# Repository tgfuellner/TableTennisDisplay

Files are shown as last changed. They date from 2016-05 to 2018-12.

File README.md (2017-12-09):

# TableTennisDisplay
Display for counting Table Tennis Matches

## Components of the Display for Version 1 with 7-Segment LEDs

* esp8266 (Wemos D1 mini)
 * Send data to LED Driver Shift Register TLC5916IN 
 * queries state of the buttons
 * controlls the OLED display
 * Can be controled by mobile phone (mqtt or http)
 * implements counting behavieour
 * Runs with 3.3V

* Powered by 12V Lead Acid Battery

* DC-DC Converter for 3.3V

* Seven Segment Displays
 * 4 Big red LED common anode for the points
 * 2 smaller green LED common kathode for the games

* LED Driver Shift Register TLC5916IN 
 * [Datasheet](http://docs-europe.electrocomponents.com/webdocs/12f7/0900766b812f7b59.pdf)

* Small OLED Display ssd1306 for umpire feedback and guidance

## Components of the Display for Version 2 with Hub75 64x32 RGB Matrix

* esp8266 (Wemos D1 mini)
 * Send data to RGB Matrix over i2c to HUB75 Controler
 * queries state of the buttons
 * controlls the OLED display
 * implements counting behavieour
 * Runs with 3.3V

* Powered by Stock 5V USB Powerbank

* HUB75 64x32 RGB Matrix

* HUB75 Controler: Arduino Mega

* Small OLED Display ssd1306 for umpire feedback and guidance

## Components of the Display for Version 3 with Hub75 64x32 RGB Matrix

* esp8266 (Wemos D1 mini)
 * Send data to RGB Matrix over i2c to HUB75 Controler
 * queries state of the buttons
 * controlls the OLED display
 * implements counting behavieour
 * Runs with 3.3V

* Powered by Stock 5V USB Powerbank

* HUB75 64x32 RGB Matrix

* HUB75 Controler: Custom made Atmega128 board
 * See https://easyeda.com/thomas.gfuellner/TTDisplay64x32-LDrpmkwus

* Small OLED Display ssd1306 for umpire feedback and guidance

## Counting behaviour

* Game is won with 2 points difference and with more than 10 points
* Indicate who has to serve - changes every 2 points or every 1 point if a player has more than 10 points
* Recognise game won
 * write message on OLED
 * increase game count
 * after Button press: reset points and swap game display digits
* In the last game: swap side if one player reaches 5 points
 * write message to OLED
 * do swaping after pressing of a button 

## Setup
### Menu right after powering the display on

* Hold back button on Power on: Join a existing Wifi or make a own AP
* Which side serves first

### Menu after long button press
* Number of games to play:
 * default: 3 games of 5
 * 2 of 3
 * 4 of 7
 * 5 of 9
* LED Brightness

## HTTP
### Remote control over Wifi

* Press an hold right back button an power the Display on
* Choose own Network not connected to internet
* Join the Wifi Network created by the Display
 * The Name is e.g. TTDisplay3
 * Ip of Display is 192.168.4.1
* There are following actions:
 * http://192.168.4.1:8080/
 * http://192.168.4.1:8080/incrRight
 * http://192.168.4.1:8080/incrLeft
 * http://192.168.4.1:8080/decrRight
 * http://192.168.4.1:8080/decrLeft
 * http://192.168.4.1:8080/finishGame
 * http://192.168.4.1:8080/swapSide
 * http://192.168.4.1:8080/count
 * http://192.168.4.1:8080/reset
 * http://192.168.4.1:8080/rightServe
 * http://192.168.4.1:8080/leftServe
 * http://192.168.4.1:8080/setNames

## Installation
* Arduino
* https://github.com/esp8266/Arduino with Boardmanager
 * Boards manager link: http://arduino.esp8266.com/stable/package_esp8266com_index.json

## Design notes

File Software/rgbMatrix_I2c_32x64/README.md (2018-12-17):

# RGB Matrix for Atmega128

## Compile

* Arduino install: https://github.com/MCUdude/MegaCore
* Library "RGB matrix Panel"
  * sed -i 's/TIMSK1/TIMSK/' /home/thomas/Arduino/libraries/RGB_matrix_Panel/RGBmatrixPanel.cpp
  * sed -i  's/TIFR1/TIFR/' /home/thomas/Arduino/libraries/RGB_matrix_Panel/RGBmatrixPanel.cpp

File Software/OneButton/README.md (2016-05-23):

Port of the Arduino OneButton Library to esp8266 micropython
===

This libary is improving the usage of a singe button for input.
It shows how to use an digital input pin with a single pushbutton attached
for detecting some of the typical button press events like single clicks, double clicks and long-time pressing.
This enables you to reuse the same button for multiple functions and lowers the hardware invests.

This is also a sample for implementing simple finite-state machines by using the simple pattern above. 

You can find more detail on this library at
http://www.mathertel.de/Arduino/OneButtonLibrary.aspx

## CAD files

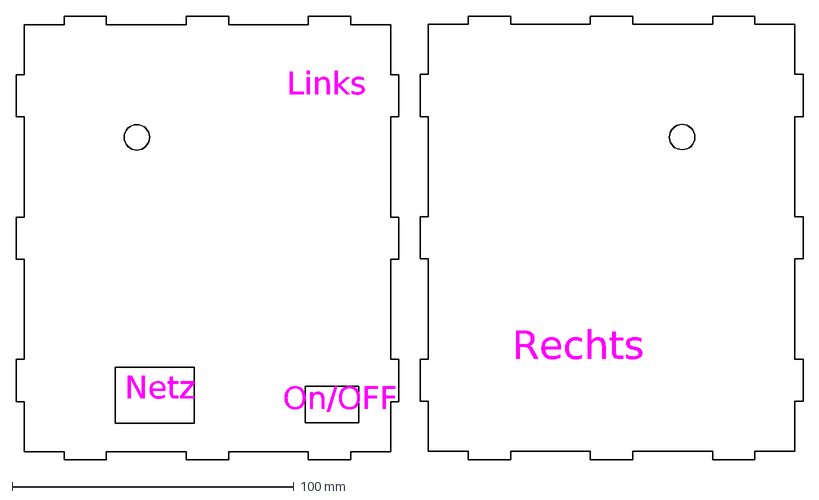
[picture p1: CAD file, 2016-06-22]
Case/bigBox-ForVersion1/sides.dxf
Links
On/OFF
Netz
Rechts

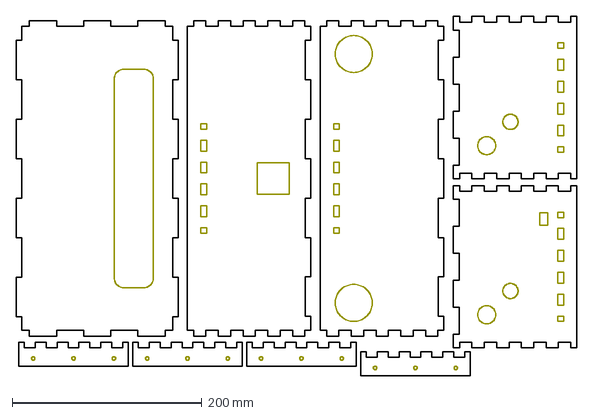
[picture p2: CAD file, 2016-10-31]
Case/rgbPanel/all-edited.dxf
590.5 x 378.0 mm

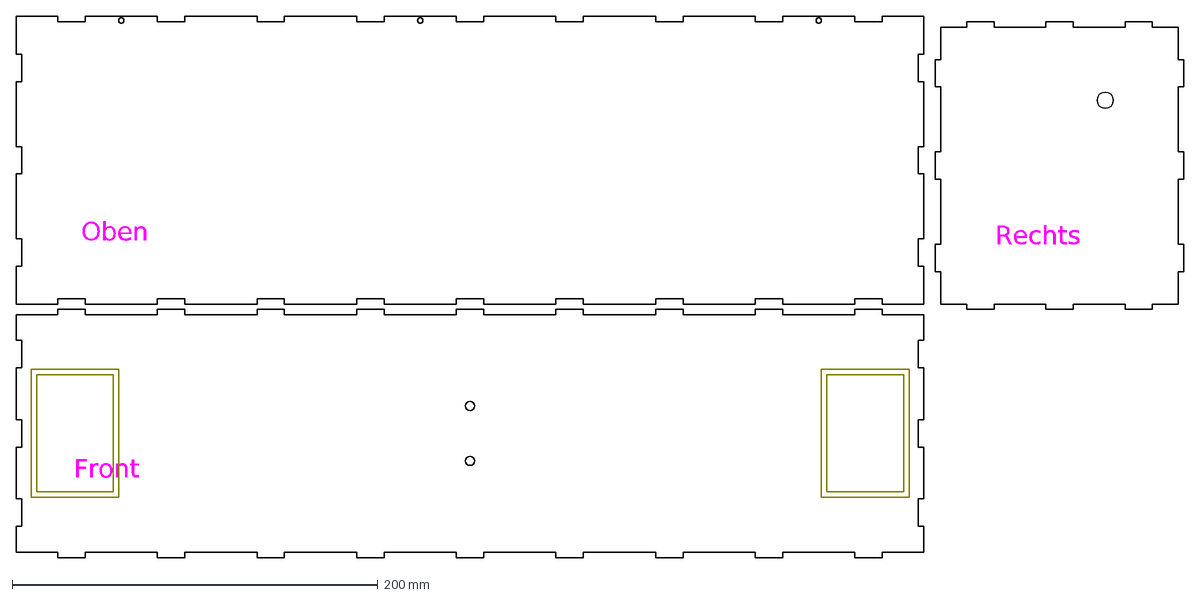
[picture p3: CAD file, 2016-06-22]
Case/bigBox-ForVersion1/box2.dxf
Oben
Front
Rechts

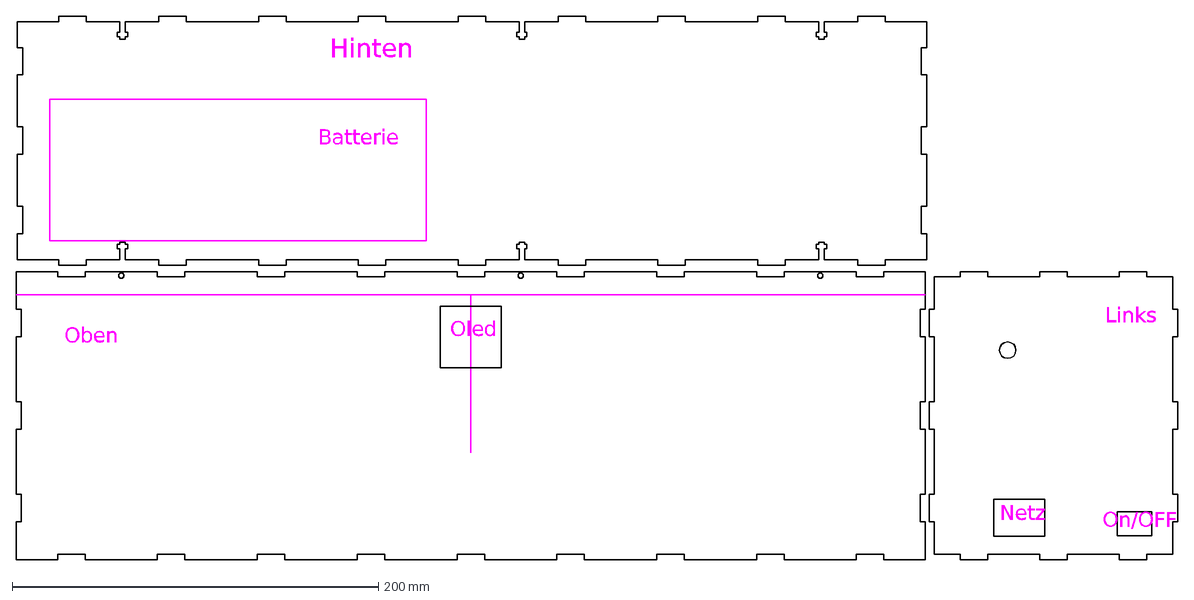
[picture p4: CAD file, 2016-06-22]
Case/bigBox-ForVersion1/box.dxf
Links
Batterie
Hinten
On/OFF
Netz
Oled
Oben

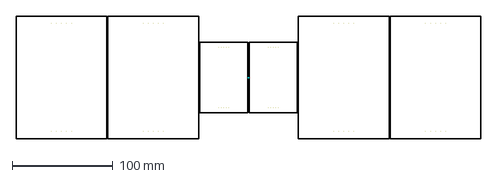
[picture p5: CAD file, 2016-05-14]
Case/bigBox-ForVersion1/front.dxf
460.6 x 121.5 mm

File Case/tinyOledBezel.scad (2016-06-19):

// Bezel for tiny Oled 0.96"
// Stiftleiste ist oben

$fn=20;
CLEARANCE=0.3;

WALL_THICKNESS=2.5;

OLED_XLENGTH=27.6 + CLEARANCE;
OLED_YLENGTH=27.8 + CLEARANCE;
OLED_XLEN_VISIBLE=25;
OLED_YLEN_VISIBLE=14.5;
OLED_FromTopToVisible=5.0+WALL_THICKNESS;
OLED_R=1;  // holes on the board

WALL_FRONT=1;
OUTER_LENGTH=WALL_THICKNESS*2 + 28;  // 28 is OLED_XLENGTH rounded up
EDGE_SIZE=4;
EDGE_ZLEN=1.9;
EDGE_PinHeight=0;

BOX_ZLENGTH=8;
R_SCREW=1.2;


module platform(x,y,dx,dy) {
    translate([x,y,WALL_FRONT+EDGE_ZLEN/2]) {
        translate([dx,dy,0]) cube([EDGE_SIZE, EDGE_SIZE, EDGE_ZLEN], center=true);
        cylinder(r1=1,r2=0.4,h=EDGE_PinHeight+EDGE_ZLEN/2);
    }
}

module screwHoles() {
translate([-1-OUTER_LENGTH/2,OLED_YLENGTH/2-5,BOX_ZLENGTH-3]) rotate([0,70,0])
    cylinder(r=R_SCREW,h=10);
translate([-1-OUTER_LENGTH/2,-OLED_YLENGTH/2+5,BOX_ZLENGTH-3]) rotate([0,70,0])
    cylinder(r=R_SCREW,h=10);
translate([1+OUTER_LENGTH/2,-OLED_YLENGTH/2+5,BOX_ZLENGTH-3]) rotate([0,-70,0])
    cylinder(r=R_SCREW,h=10);
translate([1+OUTER_LENGTH/2,OLED_YLENGTH/2-5,BOX_ZLENGTH-3]) rotate([0,-70,0])
    cylinder(r=R_SCREW,h=10);
}


difference() {
    translate([0,0,BOX_ZLENGTH/2])
        cube([OUTER_LENGTH,OUTER_LENGTH,BOX_ZLENGTH], center=true);

    translate([0,OUTER_LENGTH/2 - OLED_YLEN_VISIBLE/2 - OLED_FromTopToVisible, 0])
        cube([OLED_XLEN_VISIBLE,OLED_YLEN_VISIBLE,100], center=true);
    translate([0,0,BOX_ZLENGTH/2 + WALL_FRONT])
    cube([OLED_XLENGTH+1, OLED_YLENGTH+1,BOX_ZLENGTH], center=true);
    screwHoles();
}

platform(-OLED_XLENGTH/2+EDGE_SIZE/2, -OLED_YLENGTH/2+EDGE_SIZE/2,-1,-1);
platform(OLED_XLENGTH/2-EDGE_SIZE/2, OLED_YLENGTH/2-EDGE_SIZE/2,1,1);
platform(OLED_XLENGTH/2-EDGE_SIZE/2, -OLED_YLENGTH/2+EDGE_SIZE/2,1,-1);
platform(-OLED_XLENGTH/2+EDGE_SIZE/2, OLED_YLENGTH/2-EDGE_SIZE/2,-1,1);

difference() {
    translate([0,0,WALL_FRONT/2])
      minkowski() {
        cube([OUTER_LENGTH+1, OUTER_LENGTH+1, WALL_FRONT], center=true);
        cylinder(r=2, h=0.001);
      }

    cube([OUTER_LENGTH,OUTER_LENGTH,BOX_ZLENGTH], center=true);
}

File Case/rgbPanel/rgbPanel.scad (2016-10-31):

// Case for RGB Panel

CreateDxf = 0;    // Use with command line: openscad -DCreateDxf=1 -o all.dxf rgbPanel.scad

$fn=20;
CLEARANCE=0.3;
NOTCH_CLEARANCE = 1.002;
EPS=0.001;

WOOD_THICKNESS=6;
CASE_DEPTH_INSIDE=110;

BUTTON_R = 19/2;
BUTTON_EDGE = 35;
BACK_BUTTON_R = 16/2;
BACK_BUTTON_EDGE = 60;
POWERSWITCH_WIDTH = 8.5;
POWERSWITCH_HEIGHT = 13.2;
POWERSWITCH_EDGE = BUTTON_EDGE;

BALL_R = 39/2;
BALL_EDGE = 35;

OLED_WIDTH_HEIGHT = 33.5;
OLED_EDGE =23;

// Values for P5 Panel

RGB_PANEL_WIDTH=320;
RGB_PANEL_HEIGHT=159;
RGB_PANEL_DEPTH=14;
RGB_PANEL_R_MOUNTING_HOLES=3/2.0;
RGB_PANEL_DEPTH_MOUNTING_HOLES=10;
RGB_PANEL_EDGE_SMALL=11;
RGB_PANEL_EDGE_BIG=37;

//                                                                           +---   RGB_PANEL_EDGE_BIG
//                                                                           |
// +------------------------- RGB_PANEL_WIDTH -------------------------------+---+
// |                                                                         |   |
// |                                        o RGB_B                          |   |
// |                                                                         v   |
// |   o RGB_A                                                         RGB_C o<--+  RGB_PANEL_EDGE_SMALL
// |                                                                             | 
// |                                                                             |
// |                                                                      RGB_PANEL_HEIGHT
// |                                                                             |
// |                                                                             |
// |                                                                             |
// |                                                                             |
// |   o RGB_F                                                         RGB_D o   |
// |                                                                             |
// |                                        o RGB_E                              |
// |                                                                             |
// +-----------------------------------------------------------------------------+

// RGB_A - RGB_F: Mounting Holes width Diameter RGB_PANEL_R_MOUNTING_HOLES

MOUNT_IN = 19;
MOUNT_LENGTH = RGB_PANEL_HEIGHT - 2*RGB_PANEL_EDGE_BIG + 2*15;


// Hole for USB Powerbank
POWERBANK_HEIGHT = 41;
POWERBANK_WIDTH = 230;



// Seen from the back, referees sight
module wallLeft() {
  difference() {
    wallSide();

  }
}

module wallRight() {
  width = CASE_DEPTH_INSIDE+RGB_PANEL_DEPTH+WOOD_THICKNESS;
  height = RGB_PANEL_HEIGHT+2*WOOD_THICKNESS;

  difference() {
    wallSide();

    translate([-POWERSWITCH_EDGE+width/2, -POWERSWITCH_EDGE+height/2, 0])
      cube([POWERSWITCH_WIDTH, POWERSWITCH_HEIGHT, WOOD_THICKNESS+CLEARANCE], center=true);
  }
}

module wallSide() {
  width = CASE_DEPTH_INSIDE+RGB_PANEL_DEPTH+WOOD_THICKNESS;
  height = RGB_PANEL_HEIGHT+2*WOOD_THICKNESS;

  difference() {
    cube([width, height, WOOD_THICKNESS], center=true); 

    translate([0, (-WOOD_THICKNESS+height)/2.0, 0])
      createNotches(10, width, WOOD_THICKNESS, WOOD_THICKNESS);
    translate([0, -(-WOOD_THICKNESS+height)/2.0, 0])
      createNotches(10, width, WOOD_THICKNESS, WOOD_THICKNESS);

    translate([-(-WOOD_THICKNESS+width)/2.0-EPS, 0, 0])
      rotate(90,0,0) createNotches(6,height, WOOD_THICKNESS, WOOD_THICKNESS);

    translate([-RGB_PANEL_DEPTH+(-WOOD_THICKNESS+width)/2.0,0,MOUNT_IN/2.0])
      rotate([0,90,0]) scale(NOTCH_CLEARANCE) mountRight();

    translate([BUTTON_EDGE-width/2, BUTTON_EDGE-height/2, 0])
      cylinder(r=BUTTON_R, h=WOOD_THICKNESS+CLEARANCE, center=true, $fn=70);

    translate([BACK_BUTTON_EDGE-width/2, BACK_BUTTON_EDGE-height/2, 0])
      cylinder(r=BACK_BUTTON_R, h=WOOD_THICKNESS+CLEARANCE, center=true, $fn=70);

  }
}

module wallTop() {
    height = CASE_DEPTH_INSIDE+RGB_PANEL_DEPTH+WOOD_THICKNESS;
    difference() {
      wallTopBottom();

      translate([0, OLED_EDGE+(OLED_WIDTH_HEIGHT-height)/2])
        cube([OLED_WIDTH_HEIGHT, OLED_WIDTH_HEIGHT, WOOD_THICKNESS+CLEARANCE], center=true); 
    }
}
module wallTopBottom() {
    width = RGB_PANEL_WIDTH+2*WOOD_THICKNESS;
    height = CASE_DEPTH_INSIDE+RGB_PANEL_DEPTH+WOOD_THICKNESS;
    ly = CASE_DEPTH_INSIDE+RGB_PANEL_DEPTH+WOOD_THICKNESS;
    case_height = RGB_PANEL_HEIGHT+2*WOOD_THICKNESS;
    difference() {
      cube([width, height, WOOD_THICKNESS], center=true); 

      translate([0, (WOOD_THICKNESS-height)/2.0-EPS, 0])
        createNotches(8, width, WOOD_THICKNESS, WOOD_THICKNESS);
      translate([-(WOOD_THICKNESS+RGB_PANEL_WIDTH)/2.0,0,(-WOOD_THICKNESS+case_height)/2.0])
        rotate([90,0,90]) scale(NOTCH_CLEARANCE) wallLeft();
      translate([(WOOD_THICKNESS+RGB_PANEL_WIDTH)/2.0,0,(-WOOD_THICKNESS+case_height)/2.0])
        rotate([90,0,90]) scale(NOTCH_CLEARANCE) wallLeft();

      translate([0,-RGB_PANEL_DEPTH+(-WOOD_THICKNESS+ly)/2.0,MOUNT_IN/2.0])
        rotate([0,90,90]) scale(NOTCH_CLEARANCE) mountRight();
    }
}
module wallBottom() {
    width = RGB_PANEL_WIDTH+2*WOOD_THICKNESS;
    height = CASE_DEPTH_INSIDE+RGB_PANEL_DEPTH+WOOD_THICKNESS;

    difference() {
      wallTopBottom();

      translate([BALL_EDGE-width/2, -BALL_EDGE+height/2, 0])
        cylinder(r=BALL_R, h=WOOD_THICKNESS+CLEARANCE, center=true, $fn=70);
      translate([-BALL_EDGE+width/2, -BALL_EDGE+height/2, 0])
        cylinder(r=BALL_R, h=WOOD_THICKNESS+CLEARANCE, center=true, $fn=70);
    }
}

module wallBack() {
    width = RGB_PANEL_WIDTH+2*WOOD_THICKNESS;
    height = RGB_PANEL_HEIGHT+2*WOOD_THICKNESS;
    r=10;
    difference() {
        cube([width, height, WOOD_THICKNESS], center=true);

        translate([(WOOD_THICKNESS-width)/2.0,0,-(CASE_DEPTH_INSIDE+RGB_PANEL_DEPTH)/2.0])
          rotate([0,90,0]) scale(NOTCH_CLEARANCE) wallRight();
        translate([-(WOOD_THICKNESS-width)/2.0,0,-(CASE_DEPTH_INSIDE+RGB_PANEL_DEPTH)/2.0])
          rotate([0,90,0]) scale(NOTCH_CLEARANCE) wallRight();

        translate([0,(WOOD_THICKNESS-height)/2.0, (CASE_DEPTH_INSIDE+RGB_PANEL_DEPTH)/2.0])
          rotate([90,0,0]) scale(NOTCH_CLEARANCE) wallTopBottom();
        translate([0,-(WOOD_THICKNESS-height)/2.0, (CASE_DEPTH_INSIDE+RGB_PANEL_DEPTH)/2.0])
          rotate([90,0,0]) scale(NOTCH_CLEARANCE) wallTopBottom();

        minkowski() {
            union() {
              translate([0,POWERBANK_HEIGHT-RGB_PANEL_HEIGHT/2.0,0])
              cube([POWERBANK_WIDTH-2*r, POWERBANK_HEIGHT-2*r, WOOD_THICKNESS+CLEARANCE], center=true);
            }
            cylinder(r=r, h=WOOD_THICKNESS+CLEARANCE, $fn=70);
        }
    }
}


//                                 |
// Aussparungen mit difference     |
// erzeugen                        v
// -----+   +-----+   +-----+   +----- 
//      +---+     +---+     +---+  into
//                                 ^
//                                 |
//                                  
// <------------- width -------------> 
// count = 3  Nr of Notches to create
// z = Thickness of Material to cut

module createNotches(count, width, into, z) {
    notchWidth = width/count;

    for (n = [1:2:count]) {
      translate([notchWidth*n-width/2.0,0,0])
        cube([notchWidth, into, z+CLEARANCE], center=true);
    }
}

module mountRight() {
    xl = MOUNT_IN+WOOD_THICKNESS;
    difference() {
      cube([xl, MOUNT_LENGTH,WOOD_THICKNESS], center=true);

      translate([(xl-WOOD_THICKNESS)/2.0+EPS, 0, 0])
        rotate([0,0,90]) createNotches(10, MOUNT_LENGTH, WOOD_THICKNESS, WOOD_THICKNESS);

      translate([-WOOD_THICKNESS-RGB_PANEL_EDGE_SMALL+xl/2.0, -RGB_PANEL_EDGE_BIG+RGB_PANEL_HEIGHT/2.0, 0])
        cylinder(r=RGB_PANEL_R_MOUNTING_HOLES+CLEARANCE, h=100, center=true);
      translate([-WOOD_THICKNESS-RGB_PANEL_EDGE_SMALL+xl/2.0, RGB_PANEL_EDGE_BIG-RGB_PANEL_HEIGHT/2.0, 0])
        cylinder(r=RGB_PANEL_R_MOUNTING_HOLES+CLEARANCE, h=100, center=true);
      translate([-WOOD_THICKNESS-RGB_PANEL_EDGE_SMALL+xl/2.0, 0, 0])
        cylinder(r=RGB_PANEL_R_MOUNTING_HOLES+CLEARANCE, h=100, center=true);
    }
}

module mountLeft() {
    mirror([1,0,0]) mountRight();
}


module rgbPanel() {
  difference() {
    color("Gray") cube([RGB_PANEL_WIDTH, RGB_PANEL_HEIGHT, RGB_PANEL_DEPTH], center=true);
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

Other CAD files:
Case/bigBox-ForVersion1/Laser_Cut_Box_Generator_Script/box_generator.scad

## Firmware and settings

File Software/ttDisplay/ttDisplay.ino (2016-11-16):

/*********************************************************************
Table Tennis Score Board

Written by Thomas Gfüllner
BSD license
All text above must be included in any redistribution
*********************************************************************/

#include <SPI.h>
#include <Wire.h>
#include <Adafruit_GFX.h>
#include <Adafruit_SSD1306.h>
#include <Fonts/FreeSans24pt7b.h>
#include <Fonts/FreeSans12pt7b.h>
#include <Fonts/FreeSans9pt7b.h>
#include <OneButton.h>

#include <ESP8266WiFi.h>
#include <WiFiClient.h>
#include <DNSServer.h>
#include <ESP8266WebServer.h>
#include <WiFiManager.h>          //https://github.com/tzapu/WiFiManager
#include <ESP8266HTTPClient.h>
#include <Ticker.h>

#include <ArduinoOTA.h>


#define Sprintln(a)
// #define Sprintln(a) (Serial.println(a))
#define Sprintf(...)
// #define Sprintf(format, ...) (Serial.printf(format, __VA_ARGS__))

const char* TT_VERSION = "Version: 6";
const char* ssid = "TTDisplay3";
const char* password = "12345678";  // set to "" for open access point w/o passwortd

HTTPClient http;

Ticker timer;

#define OLED_RESET -1
Adafruit_SSD1306 display(OLED_RESET);

#if (SSD1306_LCDHEIGHT != 64)
#error("Height incorrect, please fix Adafruit_SSD1306.h!");
#endif

class Buttons {
    public:

    // Wifi dont start if D3 (GPIO0) is used
    // before Wifi setup
    OneButton buttonRight;
    OneButton buttonLeft;
    OneButton backRight;
    OneButton backLeft;
                                // second Parameter true means active Low with internal Pullup
    Buttons() : buttonRight(D3, true), buttonLeft(D4, true), backRight(D5, true), backLeft(D6, true) {
        // D3 and D4 on Wemos have external Pullup
        digitalWrite(D3, LOW);   // turn off pullUp resistor
        digitalWrite(D4, LOW);   // turn off pullUp resistor
        pinMode(D5, INPUT_PULLUP);   // turn on pullUp resistor
        pinMode(D6, INPUT_PULLUP);   // turn on pullUp resistor
        buttonRight.setClickTicks(200);
        buttonLeft.setClickTicks(200);
        backRight.setClickTicks(150);
        backLeft.setClickTicks(150);
    }

    void noButtonsCommands() {
        buttonRight.attachClick(NULL);
        buttonLeft.attachClick(NULL);
        buttonRight.attachDoubleClick(NULL);
        buttonLeft.attachDoubleClick(NULL);
        backRight.attachClick(NULL);
        backLeft.attachClick(NULL);
        backRight.attachDoubleClick(NULL);
        backLeft.attachDoubleClick(NULL);
    }
};

Buttons *b;
ESP8266WebServer *server=NULL;


// Configured at startup:
boolean leftStartetToServe = true;
int gamesNeededToWinMatch = 3;
int brightness = 0;   // darkest
bool wantToJoinNetwork = true;

// The Result:
const int MAX_GAMES = 9;
const int ZERO_RESULT = 19999;
const int END_MARK = -20000;

String nameOfPlayerWhoStartedLeft("LeftStarter");
String nameOfPlayerWhoStartedRight("RightStarter");

// Only points of Loser are stored
// If the player which startet to Serve wins, we have positive values
// otherwise negative.
// 11:4 ==> 4
// 8:11 ==> -8
// 14:12 ==> 12
// 0:11 ==> -0    (ZERO_RESULT)
int resultPlayerStartetToServe[MAX_GAMES+1] = {END_MARK};

void gameOverSwapSide();
void lastGameSwapSide();
void startCount();
void showResult();
void serverSetup();

IPAddress getIp() {
    if (WiFi.status() == WL_CONNECTED) {
        return WiFi.localIP();
    } else {
        return WiFi.softAPIP();
    }
}

String getRes(int res) {
    if (res == ZERO_RESULT) {
        return "0";
    }
    if (res == -ZERO_RESULT) {
        return "-0";
    }
    return String(res);
}

String urlencode(String str)
{
    String encodedString="";
    char c;
    char code0;
    char code1;
    char code2;
    Sprintln(String("urlencode org:")+str);
    for (int i =0; i < str.length(); i++){
      c=str.charAt(i);
      Sprintln(int(c));
      if (c == ' '){
        encodedString+= '+';
      } else if (isalnum(c) 
            || c==0xfc || c==0xf6 || c==0xe4 || c==0xdf // ü,ö,ä,ß
            || c==0xC4 || c==0xDC || c==0xD6) {  // Ä,Ü,Ö
        encodedString+=c;
      } else{
        code1=(c & 0xf)+'0';
        if ((c & 0xf) >9){
            code1=(c & 0xf) - 10 + 'A';
        }
        c=(c>>4)&0xf;
        code0=c+'0';
        if (c > 9){
            code0=c - 10 + 'A';
        }
        code2='\0';
        encodedString+='%';
        encodedString+=code0;
        encodedString+=code1;
        //encodedString+=code2;
      }
      yield();
    }
    Sprintln(encodedString);
    return encodedString;
    
}

unsigned char h2int(char c)
{
    if (c >= '0' && c <='9'){
        return((unsigned char)c - '0');
    }
    if (c >= 'a' && c <='f'){
        return((unsigned char)c - 'a' + 10);
    }
    if (c >= 'A' && c <='F'){
        return((unsigned char)c - 'A' + 10);
    }
    return(0);
}


void showServer(boolean isLeft) {
  if (isLeft) {
    display.drawFastVLine(0, 0, 64, 1);
    display.drawFastVLine(127, 0, 64, 0);
  } else {
    display.drawFastVLine(0, 0, 64, 0);
    display.drawFastVLine(127, 0, 64, 1);
  }
  display.display();
}

class ScoreOneSide {
    public:
    int games;
    int points;
    ScoreOneSide *otherSide;

    boolean winsGame() {
        if (points > 10 && otherSide->points > 9 && points - otherSide->points == 2)
            return true;
        if (points == 11 && otherSide->points <= 9)
            return true;

        return false;
    }

};

class Score {

    public:
    ScoreOneSide left;
    ScoreOneSide right;
    boolean lastGameSideChanged = false;

    Score() {
        left.otherSide = &right;
        right.otherSide = &left;
    }

    void incrGames() {
        if (left.winsGame())
            left.games++;
        else
            right.games++;
    }

    bool playersAreOnTheSideWhereTheyStarted() {
        int totalPlayedGames = left.games + right.games;

        return (totalPlayedGames % 2 == 0 && !lastGameSideChanged);
    }

    void storeResult() {
        int totalPlayedGames = left.games + right.games;
        int points = (left.points > right.points) ? right.points : -left.points;
        if (right.points == 0) {
            points = ZERO_RESULT;
        }
        if (left.points == 0) {
            points = -ZERO_RESULT;
        }

        if (lastGameSideChanged)
            points *= -1;

        if (totalPlayedGames % 2 == 1)
            points *= -1;

        resultPlayerStartetToServe[totalPlayedGames] = points;
        Sprintf("resultPlayerStartetToServe[%d] = %d\n", totalPlayedGames, points);
        // Mark end of result:
        resultPlayerStartetToServe[totalPlayedGames+1] = END_MARK;
    }

    void gameOverSwapSide() {
        storeResult();
        incrGames();
        int games = left.games;
        left.games = right.games;
        right.games = games;
        left.points = 0;
        right.points = 0;
        showScore();
    }

    void lastGameSwapSide() {
        int tmp = left.games;

        left.games = right.games;
        right.games = tmp;

        tmp = left.points;
        left.points = right.points;
        right.points = tmp;

        lastGameSideChanged = true;

        showScore();
    }

    bool leftHasToServe() {
        int player;
        int sumOfPoints = left.points + right.points;
        if (sumOfPoints < 20) 
            // First player if even
            player = int(sumOfPoints / 2) % 2;
        else
            player = sumOfPoints % 2;

        if (leftStartetToServe) 
            player = !player%2;
        else
            player = player%2;

        if (lastGameSideChanged)
            return !player;
        else
            return player;
    }


    void showScoreOnRGBMatrix() {
        Wire.beginTransmission(8); // transmit to device #8
        Wire.write(right.games);
        Wire.write(right.points);
        Wire.write(left.games);
        Wire.write(left.points);
        Wire.write(leftHasToServe()?2:1);
        int rc = Wire.endTransmission();    // stop transmitting
        Sprintf("showScoreOnRGBMatrix endTransmission=%d  points=%d\n", rc, left.points);
    }

    String getCurentResult(bool matchIsFinished) {
        String result;
        for (int i=0; resultPlayerStartetToServe[i] != END_MARK; i++) {
            result += getRes(resultPlayerStartetToServe[i]);
            result += ' ';
        }

        if (matchIsFinished) {
            return result;
        }

        if (result.length() > 0) {
            result += "| ";
        }

        if (playersAreOnTheSideWhereTheyStarted()) {
            return result + left.points + ":" + right.points;
        } else {
            return result + right.points + ":" + left.points;
        }
    }

    void indicateSending(bool isSending) {
        if (isSending) {
            const int16_t x=40, y=43;
            int16_t xlu, ylu;
            uint16_t w, h;
            const char* msg = "Sende ..";

            display.setFont(NULL);
            display.setCursor(x,y);
            display.getTextBounds((char *)msg,x,y,&xlu,&ylu,&w,&h);
            w = 5 * (2+strlen(msg));  // Bug in getTextBounds()
            display.fillRect(xlu-2,ylu-2,w+4,h+4,BLACK);
            yield();
            display.drawRect(xlu-3,ylu-3,w+6,h+6,WHITE);
            display.print(msg);
            display.display();
        } else {
            showScoreOnOled();
        }
    }

    void dweetScore(bool matchIsFinished=false) {
        if (WiFi.status() == WL_CONNECTED) {
            if (!matchIsFinished) indicateSending(true);

            const int httpPort = 80;
            const char * host = "dweet.io";

            String base("/dweet/for/");
            /*
            String uri = base+ssid+"?score="+ssid
                            +urlencode(String("<br><b>"+nameOfPlayerWhoStartedLeft+" - "
                                                       +nameOfPlayerWhoStartedRight+"</b><br/>"
                                                       +getCurentResult(matchIsFinished)));
            */
            String uri = base+ssid+"?score="+urlencode(getCurentResult(matchIsFinished));
            Sprintln(String("http://")+host+uri);

            http.begin(host, httpPort, uri);
            int httpCode = http.GET();
            if(httpCode > 0) {
                /*
                Sprintf("[HTTP] GET... code: %d\n", httpCode);

                if(httpCode == HTTP_CODE_OK) {
                    http.writeToStream(&Serial);
                    Sprintln();
                }
                */
            } else {
                Sprintf("[HTTP] GET... failed, error: %s\n", http.errorToString(httpCode).c_str());
            }

            http.end();

           if (!matchIsFinished) indicateSending(false);
        }
    }

    void showScoreOnOled() {
        display.clearDisplay();
        handleGameDecision();
        yield();
        display.setFont(&FreeSans24pt7b);
        
        if (left.points < 10)
          display.setCursor(31,32);
        else
          display.setCursor(5,32);

        display.print(left.points);
        display.print(':');
        display.print(right.points);

        yield();

        // Games in a smaller font
        display.setFont(&FreeSans12pt7b);
        display.setCursor(2,50);
        display.print(left.games);
        display.setCursor(113,50);
        display.print(right.games);

        showServer(leftHasToServe());

        display.display();
    }

    void showScore() {
        showScoreOnOled();
        yield();

        showScoreOnRGBMatrix();
        dweetScore();
    }

    void showLongPressMenu(char *message) {
        display.setFont(NULL);
        display.setCursor(25,45);
        display.print(message);
        display.setCursor(40,55);
        display.print("Taste halten");
    }

    boolean isLastPossibleGame() {
        if (left.games + right.games == gamesNeededToWinMatch*2 - 2)
            return true;

        return false;
    }

    boolean isLastGame() {
        if (left.winsGame() && left.games == gamesNeededToWinMatch-1)
            return true;
        if (right.winsGame() && right.games == gamesNeededToWinMatch-1)
            return true;

        return false;
    }

    void handleGameDecision() {
        if (left.winsGame() || right.winsGame()) {
            if (isLastGame()) {
                showLongPressMenu("   Fertig");
                b->buttonLeft.attachLongPressStart(showResult);
                b->buttonRight.attachLongPressStart(showResult);
                return;
            }

            showLongPressMenu("Seitenwechsel");
            b->buttonLeft.attachLongPressStart(::gameOverSwapSide);
            b->buttonRight.attachLongPressStart(::gameOverSwapSide);
            return;
        }

        if (isLastPossibleGame() && (left.points >= 5 || right.points >=5) && !lastGameSideChanged ) {
            showLongPressMenu("Seitenwechsel");
            b->buttonLeft.attachLongPressStart(::lastGameSwapSide);
            b->buttonRight.attachLongPressStart(::lastGameSwapSide);
            return;
        }
    }

    void count(ScoreOneSide &side, int n=1) {
        if (side.points == 0 && n <= 0)
             return;  // No negative points

        if (side.winsGame() && n>0)
            n = 0;

        side.points += n;

        showScore();
    }
};

Score theScore;

void showExpandedPoints(int r) {
  if (r > 0) {
      r = (r==ZERO_RESULT) ? 0:r;
      display.print((r>9) ? r+2 : 11);
      display.print(":");
      display.print(r);
  } else {
      r *= -1;
      r = (r==ZERO_RESULT) ? 0:r;
      display.print(r);
      display.print(":");
      display.print((r>9) ? r+2 : 11);
  }
}

void showResult() {
  b->noButtonsCommands();
  theScore.storeResult();
  
  display.clearDisplay();
  display.setFont(&FreeSans9pt7b);
  display.setCursor(0,15);
  if (theScore.left.games+theScore.right.games > 6) {
      for (int i=0; resultPlayerStartetToServe[i] != END_MARK; i++) {
          if (i>0 && i%3 == 0) 
              display.print(",\n");
          display.print(getRes(resultPlayerStartetToServe[i]));
          if (resultPlayerStartetToServe[i+1] != END_MARK) 
              display.print(", ");
      }
  } else {
      for (int i=0; resultPlayerStartetToServe[i] != END_MARK; i++) {
          if (i>0 && i%2 == 0) 
              display.print("\n");
          showExpandedPoints(resultPlayerStartetToServe[i]);
          if (resultPlayerStartetToServe[i+1] != END_MARK) 
              display.print(", ");
      }
  }
  display.display();
  theScore.dweetScore(true);
}

void handleRoot() {
	server->send(200, "text/html", nameOfPlayerWhoStartedLeft + " - " + nameOfPlayerWhoStartedRight
            + "<font size=\"+2\"> " + theScore.getCurentResult(false) +"</font>");
}

void handleIncrRight() {
    theScore.count(theScore.right);
	server->send(200, "text/html", "Ok");
}

void handleDecrRight() {
    theScore.count(theScore.right, -1);
	server->send(200, "text/html", "Ok");
}

void handleIncrLeft() {
    theScore.count(theScore.left);
	server->send(200, "text/html", "Ok");
}

void handleDecrLeft() {
    theScore.count(theScore.left, -1);
	server->send(200, "text/html", "Ok");
}

void handleFinishGame() {
    if (theScore.left.winsGame() || theScore.right.winsGame()) {
        if (theScore.isLastGame()) {
            showResult();
        } else {
            gameOverSwapSide();
        }
    }
	server->send(200, "text/html", "Ok");
}

void handleSwapSide() {
    if (theScore.isLastPossibleGame()
          && (theScore.left.points >= 5 || theScore.right.points >=5)
          && !theScore.lastGameSideChanged ) {
        lastGameSwapSide();
	    server->send(200, "text/html", "Ok");
        return;
    }
	server->send(200, "text/html", "Already swaped side");
}

void handleRightServe() {
    leftStartetToServe = false;
    startCount();
	server->send(200, "text/html", "Ok");
}

void handleLeftServe() {
    leftStartetToServe = true;
    startCount();
	server->send(200, "text/html", "Ok");
}

void handleCount() {

    String html = R"====(
<html>
<head><style>
.b{
 height:20ex;
 width:20ex;
}
</style></head>
<body>
<p>
<button class="b" onclick="req('incrRight')">+ Links</button>
&emsp;
<button class="b" onclick="req('incrLeft')">+ Rechts</button>
</p><p>
<button class="b" onclick="req('decrRight')">- Links</button>
&emsp;
<button class="b" onclick="req('decrLeft')">- Rechts</button>
</p><p><hr/></p>
<p>
<button onclick="req('finishGame')">Satz ist beendet</button>
<button onclick="req('swapSide')">Seite tauschen</button>
<button onclick="req('rightServe')">Links hat ersten Aufschlag</button>
<button onclick="req('leftServe')">Rechts hat ersten Aufschlag</button>
</p><p><hr/></p>
<button onclick="req('reset')">Neustart</button>
<script>
function req(r) {
    var t = new Date().getTime();
    var i = document.createElement("img");
    i.src = "/"+r+'?t='+t;
}
</script>
</body></html>
)====";

    server->send(200, "text/html", html);
}

void handleReset() {
	server->send(200, "text/html", "Ok");
    ESP.reset();
}

void handleSetNames() {
    nameOfPlayerWhoStartedLeft = server->arg("left");
    Sprintln(String("Name==")+nameOfPlayerWhoStartedLeft);
    nameOfPlayerWhoStartedRight = server->arg("right");

    String html= R"(<html><head><meta http-equiv="Content-Type" content="text/html;charset=iso-8859-1"></head><body>)";

    if (nameOfPlayerWhoStartedLeft.length() > 0 && nameOfPlayerWhoStartedRight.length() > 0) {
      html += String("<h2>Diese Namen wurden eingetragen:</h2><p>")
             +"Linker Spieler: "+nameOfPlayerWhoStartedLeft
             +"<br/>Rechter Spieler: "+nameOfPlayerWhoStartedRight+"</p><hr/>";
    }

    html += R"====(
<h2>Namen und Seite beim Spielbeginn:</h2>
<form action="setNames" id="form">
 <label for="left">Linker Spieler</label> 
 <input type="text" name="left" id="left" size="20" maxlength="30">

 <label for="right">Rechter Spieler</label>  
 <input type="text" name="right" id="right" size="20" maxlength="30">

 <input type="submit" value="Ok"></input>
</form></body>
)====";

    server->send(200, "text/html", html);
}


#define OK "Ok"
#define OKx 3
#define OKy 61
#define WEx 52
#define WEy 61

void showSetupMenu(char *rightMsg="Wechsel") {
  int16_t x,y;
  uint16_t w,h;

  display.setFont(&FreeSans9pt7b);
  display.getTextBounds(OK,OKx,OKy,&x,&y,&w,&h);
  display.drawRect(x-2,y-2,w+4,h+4,WHITE);
  display.setCursor(OKx,OKy);
  display.print(OK);
  
  if (rightMsg != NULL) {
      display.getTextBounds(rightMsg,WEx,WEy,&x,&y,&w,&h);
      display.drawRect(x-2,y-2,w+4,h+4,WHITE);
      display.setCursor(WEx,WEy);
      display.print(rightMsg);
  }
}

//////////////////////////////////////

void setBrightnessOnRGBMatrix(int bright) {
  Wire.beginTransmission(8); // transmit to device #8
  Wire.write(bright);
  Wire.write(bright);
  Wire.write(bright);
  Wire.write(bright);
  Wire.write(3);
  int rc = Wire.endTransmission();    // stop transmitting
  Sprintf("setBrightnessOnRGBMatrix endTransmission=%d  points=%d\n", rc, left.points);
}

void showBrightness() {
  static byte brightnessValues[] = {1, 2, 3, 4, 5};
  static char*menuTexts[] =        {"Min",      "25%",      "50%",      "75%",      "Max"};

  brightness = brightness % sizeof(brightnessValues);
  setBrightnessOnRGBMatrix(brightnessValues[brightness]);
  delay(20);

  // Geht nicht?!:
  //theScore.showScoreOnRGBMatrix();

  display.clearDisplay();
  display.setCursor(3,15);
  display.print(String("Helligkeit: ") + menuTexts[brightness]);

  showSetupMenu();
  display.display();
}

void changeBrightness() {
  brightness++;
  showBrightness();
}

void brightnessSetup() {
  showBrightness();
  b->buttonLeft.attachClick(startCount);
  b->buttonRight.attachClick(changeBrightness);
}

//////////////////////////////////////

void changeServer() {
  leftStartetToServe = !leftStartetToServe;
  showServer(leftStartetToServe);
  theScore.showScoreOnRGBMatrix();
}

void serverSetup() {
  display.clearDisplay();
  showServer(leftStartetToServe);
  theScore.showScoreOnRGBMatrix();
  display.setCursor(3,15);
  display.print("Aufschlag?");
  showSetupMenu();
  display.display();

  b->buttonLeft.attachClick(startCount);
  b->buttonRight.attachClick(changeServer);
}

//////////////////////////////////////

void showNumberOfGames(int gamesNeededToWinMatch) {
  static char*menuTexts[] = {"1 von 1?", "2 von 3?", "3 von 5?",
                             "4 von 7?", "5 von 9?"};
  display.clearDisplay();

  display.setFont(NULL);
  display.setCursor(0, 30);
  display.print("Gewinnsaetze");

  display.setFont(&FreeSans9pt7b);
  display.setCursor(3,15);
  display.print(menuTexts[gamesNeededToWinMatch-1]);

  showSetupMenu();
  display.display();
}

void changeNumberOfGames() {
  gamesNeededToWinMatch++;
  if (gamesNeededToWinMatch > 5)
      gamesNeededToWinMatch = 1;
  showNumberOfGames(gamesNeededToWinMatch);
}

void numberOfGamesSetup() {
  showNumberOfGames(gamesNeededToWinMatch);
  b->buttonLeft.attachClick(brightnessSetup);
  b->buttonRight.attachClick(changeNumberOfGames);
}

//////////////////////////////////////

void showInfoPage() {
  display.clearDisplay();

  display.setFont(NULL);
  display.setCursor(0, 0);
  display.print("IP="); display.println(getIp());

  if (wantToJoinNetwork) {
      display.println("\nTicker=");
      display.print("dweet.io ");
      display.println(ssid);
  } else {
      display.println("\nKein Ticker");
      display.println("\nnicht im Netz!");
  }

  display.setCursor(33, 50);
  display.print(TT_VERSION);

  showSetupMenu(NULL);
  display.display();
}
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
void loop() {
    if (initOTA()) {
        ArduinoOTA.handle();
    }

    b->buttonRight.tick();
    b->buttonLeft.tick();
    b->backRight.tick();
    b->backLeft.tick();
    delay(10);

    if (server) {
        server->handleClient();
    } else {
        startHttpServer();
    }

    if (thereIsANewTimoutValue) {
        showTimoutTime();
        thereIsANewTimoutValue = false;
    }

}

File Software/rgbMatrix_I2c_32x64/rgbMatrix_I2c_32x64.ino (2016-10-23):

// I2c Driver on Arduino Mega
// For 32x64 RGB LED matrix.

// NOTE THIS CAN ONLY BE USED ON A MEGA! NOT ENOUGH RAM ON UNO!
// See https://www.arduino.cc/en/Tutorial/MasterWriter

#include <EEPROM.h>
#include <Adafruit_GFX.h>   // Core graphics library
#include <RGBmatrixPanel.h> // Hardware-specific library
#include "Ubuntu_C16pt7b.h"
#include <Fonts/FreeSans9pt7b.h>
#include <Wire.h>

//           Atmega128     Atmega2560
#define OE   25 // 9
#define LAT  24 // 10
#define CLK  23 // 11
#define A    28 // A0
#define B    29 // A1
#define C    30 // A2
#define D    31 // A3

RGBmatrixPanel matrix(A, B, C, D, CLK, LAT, OE, false, 64);

uint16_t WHITE;
uint16_t BLUE;
uint16_t BLACK;
uint16_t RED;
uint16_t GREEN;
uint16_t GREETING;

bool newDataArived = false;


int leftGames = 0;
int leftPoints = 0;

int rightGames = 0;
int rightPoints = 0;

enum State {
    timeout = 0,
    left = 1, right = 2,    // Side to serve
    brightnessAdjust = 3,   // In leftGames is brightness value
};
State state = timeout;


void setBrightness(int brightness) {
  WHITE = matrix.Color333(brightness,brightness,brightness);
  BLUE = matrix.Color333(0,0,brightness);
  BLACK = matrix.Color333(0,0,0);
  RED = matrix.Color333(brightness,0,0);
  GREEN = matrix.Color333(0,brightness,0);
  GREETING = matrix.Color333(brightness,0,0);
}



#define CONFIG_VERSION "td1"
#define CONFIG_START 32
struct StoreStruct {
  char version[4];  // This is for mere detection if they are your settings
  int brightness;   // The variables of your settings
};
StoreStruct storage = {CONFIG_VERSION, 1};

void loadConfig() {
  // To make sure there are settings, and they are YOURS!
  // If nothing is found it will use the default settings.
  if (EEPROM.read(CONFIG_START + 0) == CONFIG_VERSION[0] &&
      EEPROM.read(CONFIG_START + 1) == CONFIG_VERSION[1] &&
      EEPROM.read(CONFIG_START + 2) == CONFIG_VERSION[2]) {

    for (unsigned int t=0; t<sizeof(storage); t++)
      *((char*)&storage + t) = EEPROM.read(CONFIG_START + t);

    setBrightness(storage.brightness);
  }
}

void saveConfig() {
  for (unsigned int t=0; t<sizeof(storage); t++)
    EEPROM.write(CONFIG_START + t, *((char*)&storage + t));
}



void showScore() {
  digitalWrite(OE, HIGH);   // Stop led flashing

  // fill the screen with 'black'
  matrix.fillScreen(BLACK);
  
  matrix.setFont(&Ubuntu_C16pt7b);
  matrix.setTextWrap(false); // Don't wrap at end of line - will do ourselves

  int x;
  uint16_t color;

  if (state == timeout) {
      if (leftPoints < 10) {
          x = 27;
      } else {
          x = 18;
      }
      color = GREEN;
      if (leftPoints < 11) {
          color = RED;
      }
      matrix.setCursor(x, 26);
      matrix.setTextColor(color);
      matrix.print(leftPoints);
      digitalWrite(OE, LOW);
      return;
  }

  // Left Points and Games
  if (leftPoints < 10) {
      x = 8;
      color = GREEN;

      matrix.setFont(&FreeSans9pt7b);
      matrix.setTextColor(RED);
      matrix.setCursor(-1, 31);
      matrix.print(leftGames);
  } else {
      color = RED;
      x = 0;

      matrix.setFont(NULL);
      matrix.setTextColor(RED);
      matrix.setTextSize(1);     // size 1 == 8 pixels high
      matrix.setCursor(1, 24);
      matrix.print(leftGames);
  }
  matrix.setFont(&Ubuntu_C16pt7b);
  matrix.setCursor(x, 21);
  matrix.setTextColor(color);
  matrix.print(leftPoints);

  matrix.setCursor(28, 19);
  matrix.setTextColor(RED);
  matrix.print(":");

  if (rightPoints < 10) {
      x = 43;
      color = GREEN;

      matrix.setFont(&FreeSans9pt7b);
      matrix.setTextColor(RED);
      matrix.setCursor(55, 31);
      matrix.print(rightGames);
  } else {
      x = 38;
      color = RED;

      matrix.setFont(NULL);
      matrix.setTextColor(RED);
      matrix.setTextSize(1);     // size 1 == 8 pixels high
      matrix.setCursor(58, 24);
      matrix.print(rightGames);
  }
  matrix.setFont(&Ubuntu_C16pt7b);
  matrix.setTextColor(color);
  matrix.setCursor(x, 21);
  matrix.print(rightPoints);


  // Server
  if (state==left) {
      matrix.fillCircle(14,27,3,GREEN);
  } else if (state==right) {
      matrix.fillCircle(49,27,3,GREEN);
  }

  digitalWrite(OE, LOW);
}

void showGreeting() {
  digitalWrite(OE, HIGH);   // Stop led flashing

  // fill the screen with 'black'
  matrix.fillScreen(BLACK);
  
  matrix.setFont(&Ubuntu_C16pt7b);
  matrix.setTextWrap(false); // Don't wrap at end of line - will do ourselves


  matrix.setCursor(0, 26);
  matrix.setTextColor(GREETING);
  matrix.print("Hallo");

  digitalWrite(OE, LOW);
}

void afterValueReceived() {
  if (state==brightnessAdjust) {
      setBrightness(leftGames);
      storage.brightness = leftGames;
      saveConfig();
      return;
  }

  newDataArived = true;
}

void receiveEvent(int howMany) {
  leftGames = Wire.read();
  leftPoints = Wire.read();
  rightGames = Wire.read();
  rightPoints = Wire.read();
  state = static_cast<State>(Wire.read());

  afterValueReceived();
}

void testScore(int lg,int lp, int rg,int rp, State s) {
  leftGames = lg;
  leftPoints = lp;
  rightGames = rg;
  rightPoints = rp;
  state = s;

  afterValueReceived();
}


void setup() {
  Wire.begin(8);                // join i2c bus with address #8
  Wire.onReceive(receiveEvent); // register event

  matrix.begin();
  setBrightness(1);
  loadConfig();
  
  //testScore(1,0, 0,0, brightnessAdjust);
  //testScore(3,11, 2,9, left);
  showGreeting();
}


void loop() {
  delay(10);
  if (newDataArived) {
      showScore();
      newDataArived = false;
  }
}

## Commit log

2016-05-14 Aus dem Bastel Repo übernommen
    [box.dxf, box2.dxf, box_generator.scad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]
2016-05-23 Port of OneButton Arduino Lib to micropython
2016-05-26 Attiny wird nicht mehr gebraucht
2016-05-30 Swap sides in last game
    [ttDisplay.ino]
2016-06-04 Aussparungen für Taster und Einschalter
    [box.dxf, box2.dxf]
2016-06-05 ZUm mounten des Oleds
    [tinyOledBezel.scad]
2016-06-06 Frontblende und Befestigungslöcher
    [tinyOledBezel.scad]
2016-06-06 smaller pins, edges out of the way, adjusted window
    [tinyOledBezel.scad]
2016-06-06 Netzstecker, Schalter auf die Seite
    [box.dxf]
2016-06-06 Kleine Segement Anzeigen an den Rand, 2 LEDs
    [box.dxf, box2.dxf]
2016-06-11 Befestigungslöcher zum fraesen
    [box2.dxf]
2016-06-15 Schaltplan, Treiber IC und Segment Displays
    [tt-display.sch]
2016-06-19 ESP8266 Beschaltung
    [tt-display.sch]
2016-06-19 Oled Fenster nach unten verschoben
    [tinyOledBezel.scad]
2016-06-19 Oled Fenster wieder nach oben
    [tinyOledBezel.scad]
2016-06-19 Oled Aussparung
    [box.dxf]
2016-06-22 sheetCam jobs and deleted unwanted outside dxf lines
    [box.dxf, box2.dxf]
2016-07-03 LED Ziffern funktioinieren
2016-07-04 LEDs zeigen den aktuellen Score
2016-07-04 Anzeige der Batteriespannung
2016-07-06 Wifi AP mit Http Server
    Button auf D3 erst nach Wifi Start initialisieren!
2016-07-09 Ap und Station Mode konfigurierbar
2016-07-10 Fixed Problem left richt player Result
    [ttDisplay.ino]
2016-07-11 Batterie Spannung neu kalibriert. Abwechselnd Bat Status und Spannung
2016-07-11 Musste Widerstand für Bat Spannungsmessung erhöhen
    [tt-display.sch]
2016-07-13 Eingabe der Namen, Umlaut Probleme
    [ttDisplay.ino]
2016-08-09 Driver for 64x32 rgb Matrix
2016-08-09 I2C Slave
2016-08-10 Stop aufblitzende LEDs bei Übergängen
2016-08-11 moved Case Version 1 into own Subdir
    [box.dxf, box2.dxf, box_generator.scad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]
2016-08-11 Moved into Subdir
    [box.dxf, box2.dxf, box_generator.scad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]
2016-08-11 simple Box ohne Zinken und Aussparungen
    [rgbPanel.scad]
2016-08-12 Aussparung für Powerbank
    [rgbPanel.scad]
2016-08-15 Alle aussere Zinken
    [rgbPanel.scad]
2016-08-15 Mount right
    [rgbPanel.scad]
2016-08-15 All mountings
    [rgbPanel.scad]
2016-08-16 Akku Aussparung in die Rückseite verschoben, DXF Ausgabe
    [rgbPanel.scad]
2016-08-20 Gehäuse mit allen Aussparungen
    [rgbPanel.scad]
2016-08-21 scad dxf Ausgabe mit librecad editiert: layer Aufteilung
    [all-edited.dxf]
2016-08-22 Schaltplan fuer RGB Matrix 64x32
    [tt-display.kicad_pcb, tt-display.sch]
2016-08-26 Extra Undo Buttons
2016-08-28 Zurueck Button im Schaltplan
    [tt-display.sch]
2016-09-20 Helligkeit der RGBMatrix ist nun einstellbar
2016-10-31 Backbutton und On/off hinzugefuegt
    [all-edited.dxf, rgbPanel.scad]
2016-11-07 Added Back Button und Schalter
2016-11-07 Dweet nur Ergebnis - keine Namen und Html
    Praktikabler: Name wird auf freeboard eingestellt
2016-11-07 Hole Ip dynamisch und starte HttpServer nach Aufschlag Bestimmung
2016-11-09 swapSide und finischGame ueber http
    [ttDisplay.ino]
2016-11-11 horizontaler Space zwischen Buttons
2016-11-11 Starte HttpServer ohne Button
2016-11-12 Aufschlagsbestimmung über Http und OTA update
